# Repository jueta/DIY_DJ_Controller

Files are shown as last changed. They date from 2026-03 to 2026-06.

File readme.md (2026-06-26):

# DIY DJ Controller



Homemade CDJ-style DJ controller with a 3D-printed enclosure, hand-built electronics, and custom firmware.

This repository documents:
- the current stable Mixxx prototype
- the firmware and Mixxx mapping that make it work
- the next hardware direction for a cleaner v2 build
- open-source hardware, firmware, and documentation for builders who want to contribute

DIY DJ controller with blue buttons

DIY DJ controller with tools

<table>
  <tr>
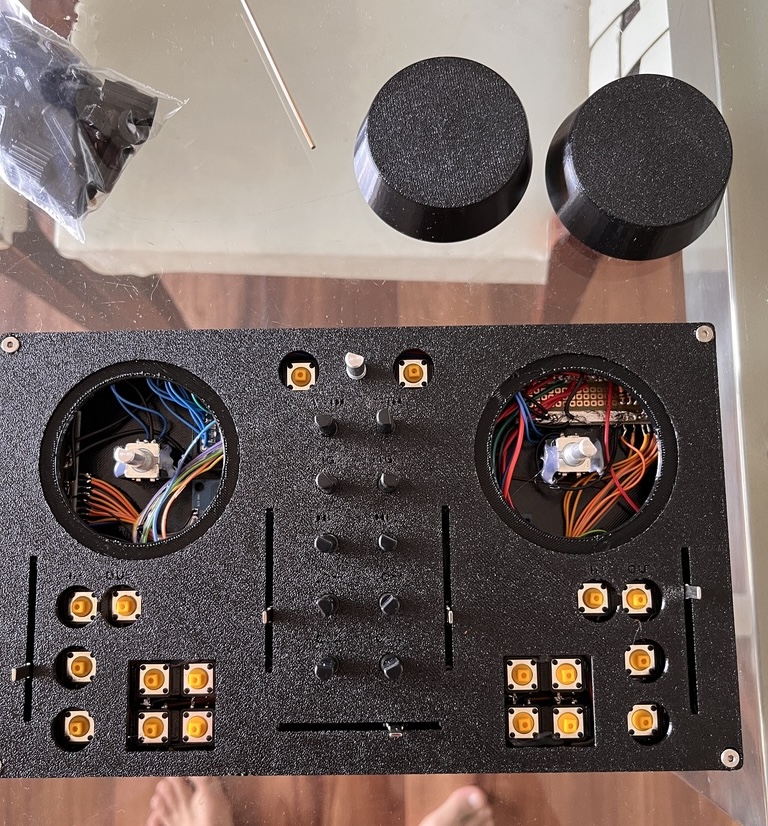
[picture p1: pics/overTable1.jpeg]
Prototype top view before final buttons
    <td></td>
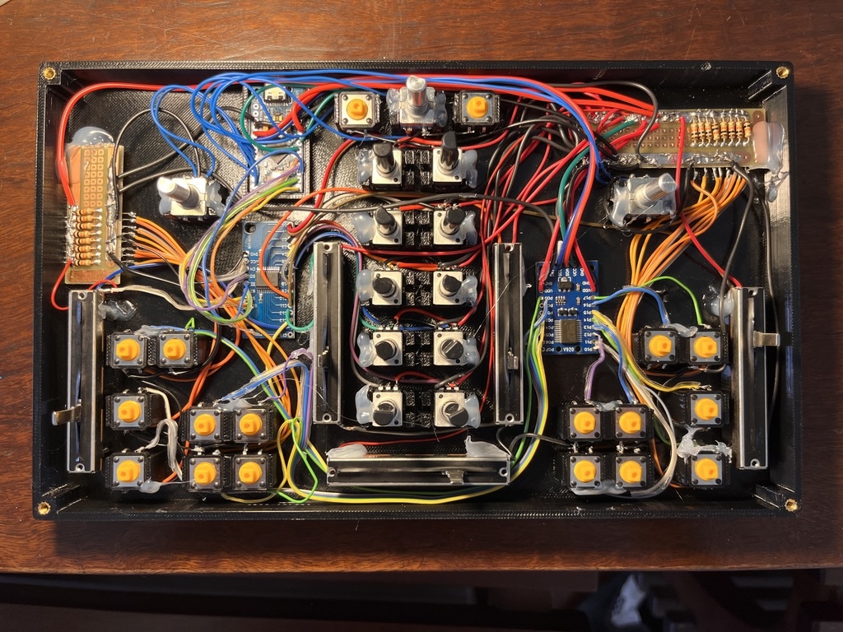
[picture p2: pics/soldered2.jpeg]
Hand-wired controller electronics
    <td></td>
  </tr>
  <tr>
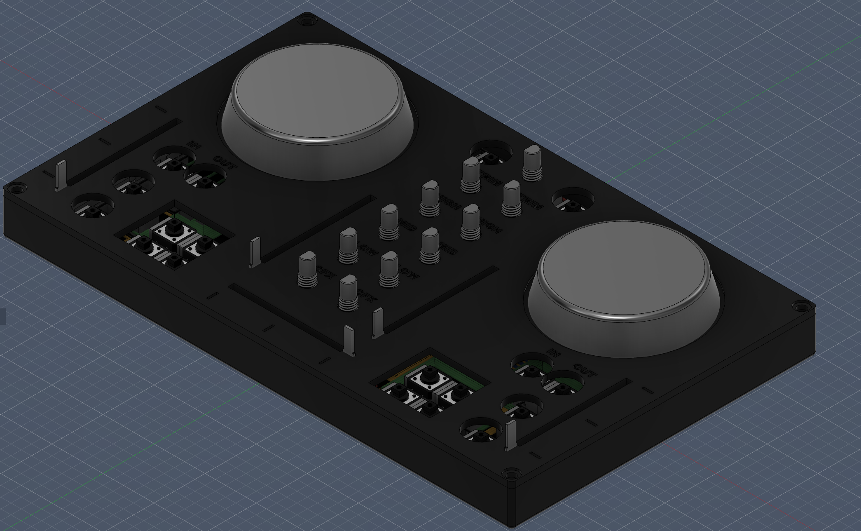
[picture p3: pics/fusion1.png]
Fusion 360 top assembly render
    <td></td>
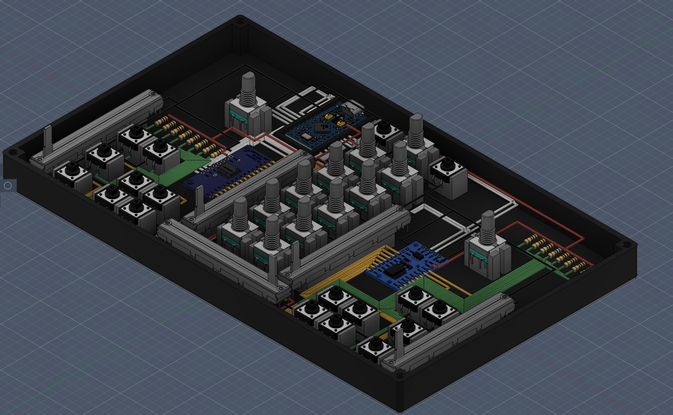
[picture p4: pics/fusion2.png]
Fusion 360 internal assembly render
    <td></td>
  </tr>
</table>

## Status

- `v1` is the stable Mixxx-focused version
- the controller has been built, flashed, and used successfully as a working prototype
- Rekordbox was tested, but the jog wheels never became usable enough for a real workflow
- because of that, Rekordbox is not a supported target for this hardware revision

## Current Version

- `MCU`: SparkFun Pro Micro / ATmega32U4
- `Firmware`: PlatformIO + Arduino + `MIDIUSB`
- `Inputs`: `PCF8575` for buttons, `74HC4067` for analog controls, 3 rotary encoders
- `Mechanical`: custom 3D-printed enclosure designed in Fusion 360
- `Software target`: Mixxx

The current prototype includes:
- two-deck transport and loop control
- EQ, filter, gain, volume, tempo, and crossfader control
- jog wheels
- music browsing and load controls

## V1 Hardware Summary

- `MCU`: SparkFun Pro Micro / ATmega32U4
- `Button expander`: `PCF8575` for 16 buttons
- `Analog mux`: `74HC4067` for 15 potentiometers
- `Encoders`: 3 total
  - 1 browse encoder
  - 2 jog wheel encoders
- `Encoder model`: Alps `EC11E` vertical rotary encoder, `H20mm`
- `Button model`: Omron `B3F-40xx`, 12x12 mm THT tactile switch
- `Direct buttons on MCU`: `A1`, `A2`, `A3`
- `Potentiometers`: 15 total
  - `Linear model`: `B103` 75 mm linear slide potentiometer, 10 kOhm
  - `Rotary model`: TT Electronics `P0915N` vertical rotary potentiometer

## V1 Materials List

This is the practical parts list for rebuilding the current working v1 prototype.

| Qty | Material | Notes |
| --- | --- | --- |
| 1 | 🧠 Microcontroller | Arduino Pro Micro - ATmega32U4 - USB Type C |
| 18 | 🔘 Buttons | B3F-4055 - 12x12x7.3mm |
| 3 | 🔄 Rotary Encoders | EC11 - 15mm shaft lenght - D shaft - without push button |
| 10 | 🎛️ Rotary Potentiometers | R0902N - B103 - 10kΩ - 23mm shaft lenght - D shaft |
| 5 | 🎚️ Slide Potentiometers | 60mm - B103 - 10kΩ - 15mm handle lenght |
| 1 | 🔘 Buttons pin expander | `PCF8575` / HW-331 16-bit I2C IO expander module |
| 1 | 🎛️ Potentiometers pin expander | `CD74HC4067` / `74HC4067` 16-channel analog multiplexer module |
| 1 | 3D-printed enclosure body | `3D models/DIY_CDJ_body.stl`. |
| 1 | 3D-printed enclosure lid | `3D models/DIY_CDJ_lid.stl`. |
| 1 each | 3D-printed caps and control parts | `crossfader.stl`, `cue.stl`, `encoder.stl`, `joggingWheel.stl`, `knob.stl`, `performance-pad.stl`, and `play-pause.stl`. |
| As needed | Hookup wire, solder, and 2.54 mm headers | The stable v1 prototype is hand-wired, not PCB-based. |

The firmware currently defines 3 direct music-selection inputs on `A1`, `A2`, and `A3`, but the KiCad v1 schematic places 18 tactile switches total. Add one extra switch if you wire all 3 direct inputs. The schematic also contains 16 resistor placeholders with no values or footprints assigned yet, so treat those as schematic TODOs rather than an order-ready BOM line.

## V1 Wiring Summary

These are the important firmware-defined connections for the current working Mixxx version.

### Wiring Diagrams

<p>
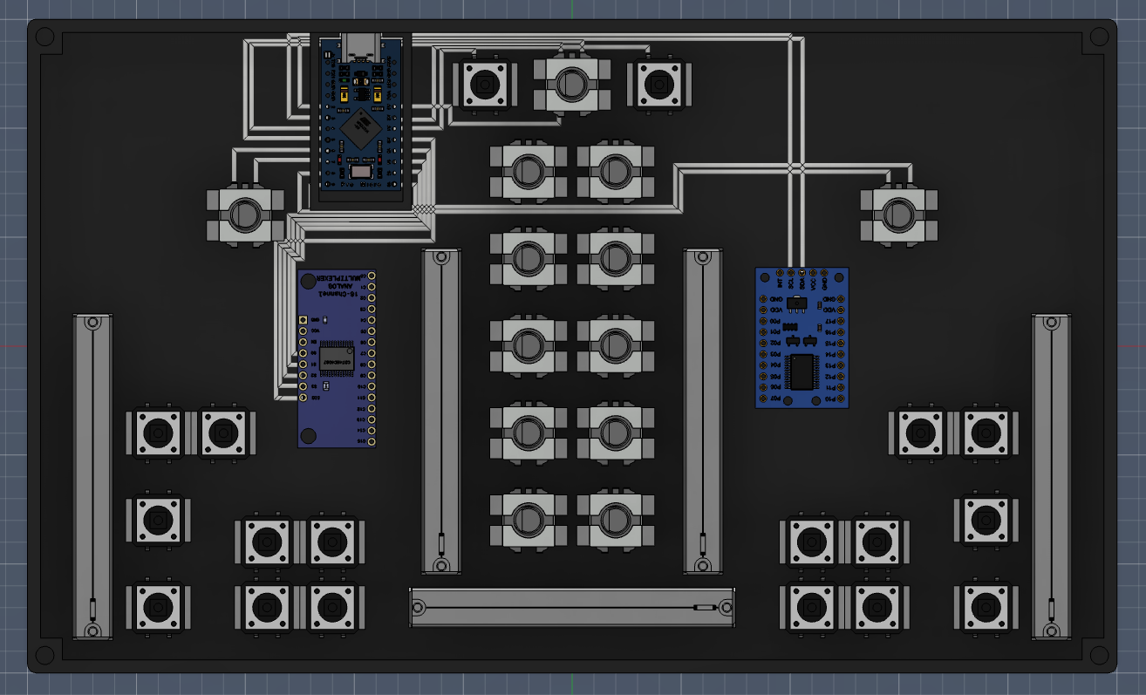
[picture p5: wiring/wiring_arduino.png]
Arduino wiring
  
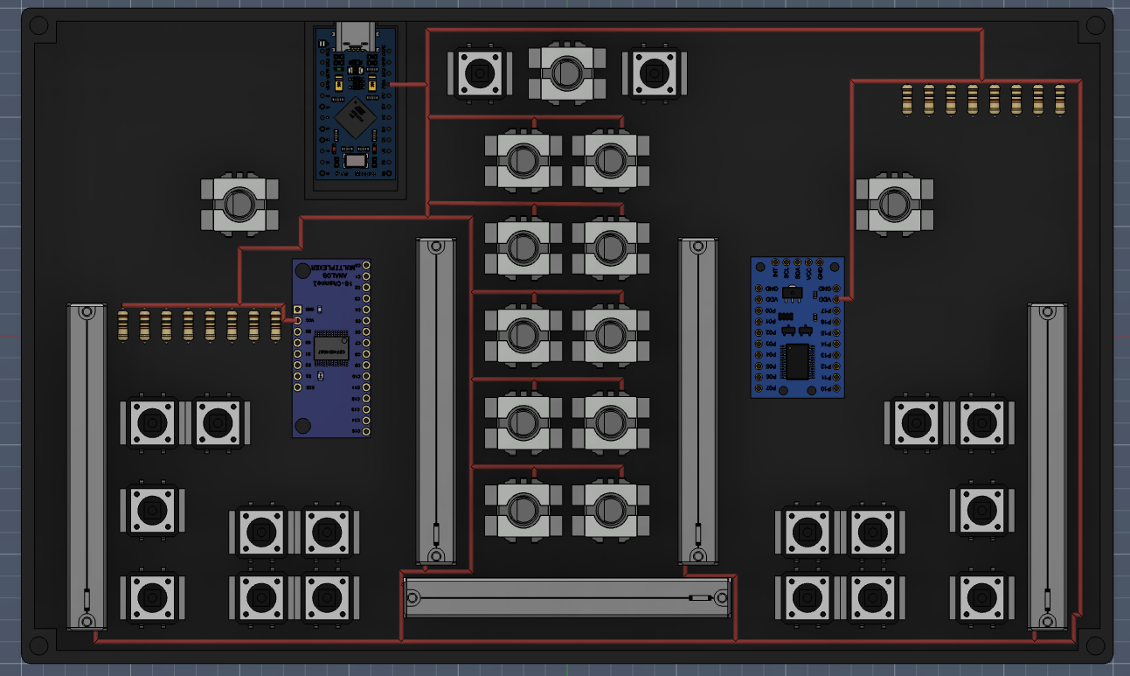
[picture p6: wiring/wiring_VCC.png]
VCC wiring
  
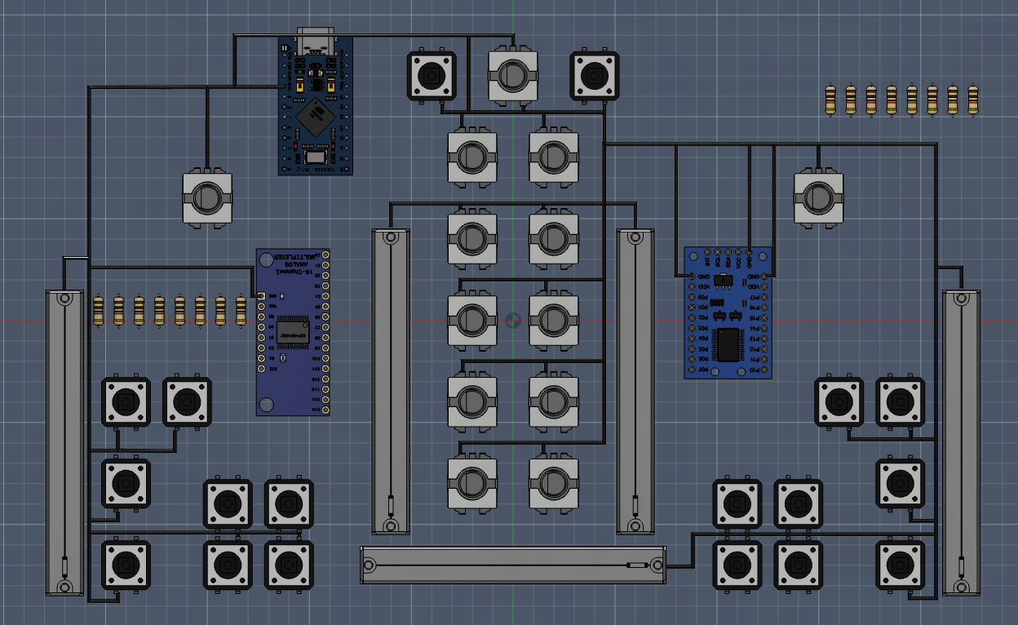
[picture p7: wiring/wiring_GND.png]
GND wiring
  
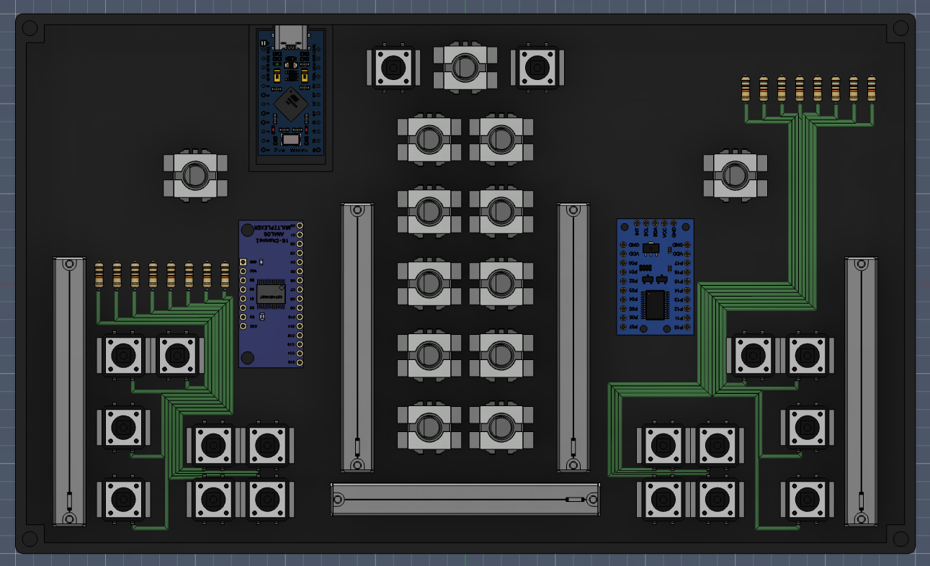
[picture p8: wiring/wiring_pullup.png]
Pull-up wiring
  
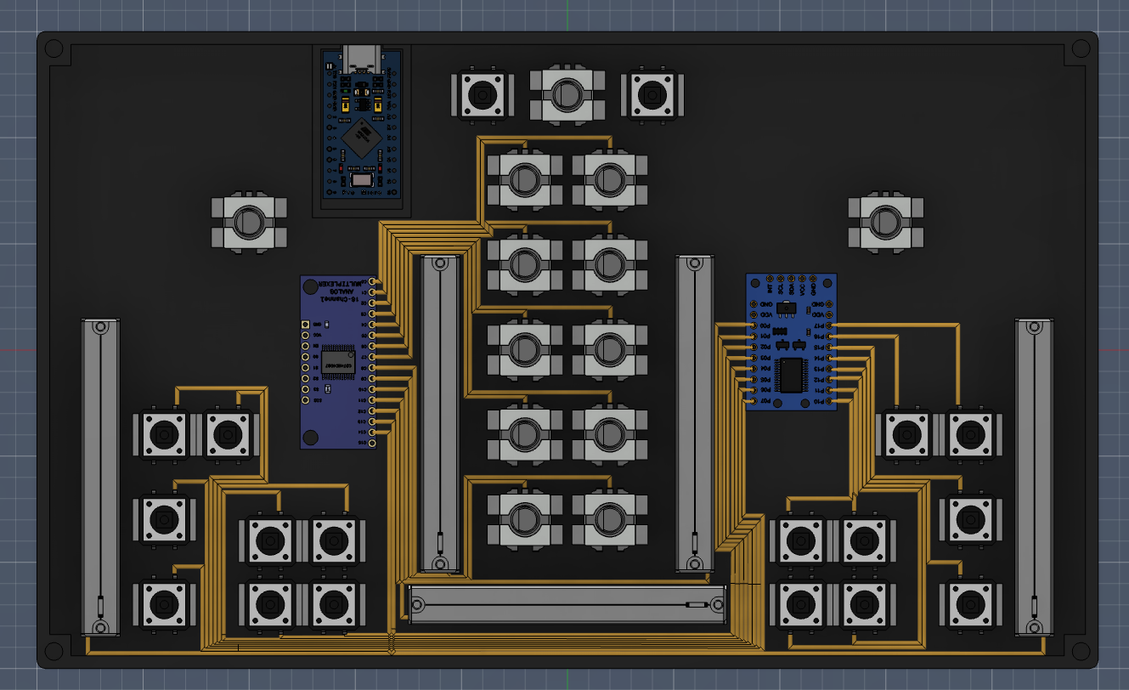
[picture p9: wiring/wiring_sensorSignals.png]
Sensor signal wiring
  
</p>

### I2C / Button Expander

- `SDA` -> pin `2`
- `SCL` -> pin `3`
- `PCF8575` address is auto-detected on boot in the `0x20` to `0x27` range

### 74HC4067 Multiplexer

- `MUX signal` -> `A0`
- `S0` -> pin `15`
- `S1` -> pin `14`
- `S2` -> pin `16`
- `S3` -> pin `10`

### Rotary Encoders

- `Browse encoder` -> pins `4` and `5`
- `Jog wheel 1` -> pins `8` and `9`
- `Jog wheel 2` -> pins `6` and `7`

### Direct Buttons

- `A3` -> note `76`
- `A2` -> note `77`
- `A1` -> note `78`

## V1 Current Input Map

### PCF8575 Buttons

- `Button 0` -> Deck 1 Loop Out
- `Button 1` -> Deck 1 Loop In
- `Button 2` -> Deck 1 Hotcue 3
- `Button 3` -> Deck 1 Hotcue 4
- `Button 4` -> Deck 1 Hotcue 1
- `Button 5` -> Deck 1 Hotcue 2
- `Button 6` -> Deck 1 Cue
- `Button 7` -> Deck 1 Play/Pause
- `Button 8` -> Deck 2 Hotcue 4
- `Button 9` -> Deck 2 Hotcue 3
- `Button 10` -> Deck 2 Hotcue 1
- `Button 11` -> Deck 2 Hotcue 2
- `Button 12` -> Deck 2 Cue
- `Button 13` -> Deck 2 Play/Pause
- `Button 14` -> Deck 2 Loop In
- `Button 15` -> Deck 2 Loop Out

### Potentiometers

- `Pot 0 / CC 10` -> Deck 1 Gain
- `Pot 1 / CC 11` -> Deck 2 Gain
- `Pot 2 / CC 12` -> Deck 1 High EQ
- `Pot 3 / CC 13` -> Deck 2 High EQ
- `Pot 4 / CC 14` -> Deck 1 Mid EQ
- `Pot 5 / CC 15` -> Deck 2 Mid EQ
- `Pot 6 / CC 16` -> Deck 1 Low EQ
- `Pot 7 / CC 17` -> Deck 2 Low EQ
- `Pot 8 / CC 18` -> Deck 1 Filter
- `Pot 9 / CC 19` -> Deck 2 Filter
- `Pot 10 / CC 20` -> Deck 2 Volume
- `Pot 11 / CC 21` -> Deck 2 Tempo
- `Pot 12 / CC 22` -> Deck 1 Volume
- `Pot 13 / CC 23` -> Crossfader
- `Pot 14 / CC 24` -> Deck 1 Tempo

### Browser And Jog Controls

- `Browse encoder / CC 25` -> library scroll
- `A1 / note 78` -> Load selected track to Deck 1
- `A2 / note 77` -> Load selected track to Deck 2
- `A3 / note 76` -> Enter or expand selected folder
- `Jog wheel on pins 8/9 / CC 26` -> currently mapped to Deck 2
- `Jog wheel on pins 6/7 / CC 27` -> currently mapped to Deck 1

## V1 Firmware

The current firmware lives in `CDJ_firmware/src/main.cpp`.

### Current Behavior

- auto-detects the `PCF8575` on boot
- configures the expander pins as input pull-high
- reads 16 buttons through the `PCF8575`
- reads 15 analog controls through the `74HC4067`
- reads 3 rotary encoders
- reads direct top buttons on `A1`, `A2`, and `A3`
- sends MIDI note and CC messages through `MIDIUSB`
- uses an additional filter on the browse encoder to reduce event spam in Mixxx

### Build Target

`CDJ_firmware/platformio.ini` currently targets:

```ini
[env:sparkfun_promicro16]
platform = atmelavr
board = sparkfun_promicro16
framework = arduino
lib_deps =
  arduino-libraries/MIDIUSB @ ^1.0.5
```

## Repo Layout

- `CDJ_firmware/` - firmware source and PlatformIO config
- `controllers/mixx_Mapping/` - Mixxx XML and JS mapping
- `controllers/rekordbox/` - Rekordbox mapping reference and notes
- `pics/` - renders and prototype photos
- `reference circuits/` - circuit reference images
- `PCB/` - KiCad schematic, PCB, and custom symbols/footprints
- `3D models/` - printable parts and Fusion 360 source archive
- `CONTRIBUTING.md` - contribution guide
- `.github/` - issue templates, pull request template, and CI workflow

## Source Of Truth

- `Firmware`: `CDJ_firmware/src/main.cpp`
- `Mixxx XML mapping`: `controllers/mixx_Mapping/DJC-DIY.midi.xml`
- `Mixxx JS mapping`: `controllers/mixx_Mapping/DJC-DIY-scripts.js`

For exact control behavior, use those files instead of this README.

## Contributing

Contributions are welcome. The most useful contributions right now are practical build reports, Mixxx mapping fixes, firmware cleanup, PCB review, parts substitutions, enclosure fit notes, and documentation improvements.

Before starting a large hardware or firmware change, open an issue so the direction can be discussed. Small documentation fixes can go straight to a pull request.

Useful starter work:

- test the current Mixxx mapping on another OS or Mixxx version
- document compatible Pro Micro clones, encoders, buttons, and potentiometers
- improve wiring photos or assembly notes
- review the KiCad v1 schematic and PCB TODOs
- add real build notes for 3D-print settings and fit adjustments

See `CONTRIBUTING.md` for the full workflow and pull request checklist.

## Getting Started

### Firmware

1. Install [PlatformIO](https://platformio.org/) in VS Code.
2. Open `CDJ_firmware/`.
3. Connect the SparkFun Pro Micro by USB.
4. Build or upload:

```bash
pio run
pio run --target upload
```

### Mixxx

Copy these files into your Mixxx controller mapping folder:

- `controllers/mixx_Mapping/DJC-DIY.midi.xml`
- `controllers/mixx_Mapping/DJC-DIY-scripts.js`

Then enable the mapping in Mixxx.

## Important Notes

- The stable path for this project is Mixxx, not Rekordbox.
- The prototype is still hand-wired and not PCB-based yet.
- The current jog wheel assignment is swapped between physical control and deck mapping.
- Rekordbox support should be treated as future hardware research, not a feature of this version.

## V2 Plan

V2 is a hardware redesign focused on one goal: keep a single `USB-C` cable to the computer and add a built-in `3.5 mm` headphone cue output.

- `Master` stays on the computer side
- the controller provides only `Headphones / Cue`
- the project stays Mixxx-first

### Electronics Plan

- `Prototype MCU`: `SparkFun Thing Plus ESP32-S3`
- `Custom PCB MCU`: `ESP32-S3-WROOM-1`
- `Headphone audio`: `Adafruit TLV320DAC3100` or equivalent small I2S headphone DAC/codec
- `External ports`: one `USB-C`, one `3.5 mm TRS` headphone jack
- `Existing controls to keep initially`: `PCF8575`, `74HC4067`, jog encoders, browse encoder, buttons, and potentiometers

### Core Connections

- `USB-C` -> `ESP32-S3`
- `ESP32-S3 I2S` -> `TLV320DAC3100` audio data
- `ESP32-S3 I2C` -> `TLV320DAC3100` configuration
- `TLV320DAC3100` -> `3.5 mm TRS` headphone jack
- `ESP32-S3` -> existing control hardware

### Firmware Work

- port the controller logic from `ATmega32U4` to `ESP32-S3`
- expose one composite USB device with `MIDI + audio`
- keep the current control behavior as close to `v1` as possible
- send Mixxx cue audio to the headphone DAC

### Rekordbox Note

`ESP32-S3` is a much better platform for future USB experiments, but it does not guarantee Rekordbox compatibility or working jog wheels. V2 should still be treated as a Mixxx-first design.

## License

This project uses separate licenses by file type:

| Files | License |
| --- | --- |
| Firmware and controller mappings | GNU General Public License v3.0 only (`GPL-3.0-only`) |
| PCB, wiring, CAD, and 3D hardware design files | CERN Open Hardware Licence Version 2 - Strongly Reciprocal (`CERN-OHL-S-2.0`) |
| Documentation, photos, videos, and other media | Creative Commons Attribution 4.0 International (`CC-BY-4.0`) |

See `LICENSE.md`, `LICENSE-SOFTWARE.txt`, `LICENSE-HARDWARE.txt`, and `LICENSE-DOCS.txt` for details.

This project was inspired by my friend [@mandiclab](https://github.com/mandiclab) and the [djc-diy](https://github.com/mandiclab/djc-diy) project.

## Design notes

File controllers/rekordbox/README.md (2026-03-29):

# Rekordbox Mapping

This folder contains a Rekordbox mapping reference for the DIY DJ controller.

## Important Limitation

Rekordbox supports MIDI Learn and can export/import MIDI mappings as CSV, but AlphaTheta does not publicly document the CSV schema. That means this folder provides:

- a complete mapping reference CSV for manual setup in Rekordbox
- a workflow for exporting your own Rekordbox CSV and adapting it later

If you export a sample MIDI CSV from your installed Rekordbox version, it can be converted into a true importable file using the same mapping in this folder.

## Intended Behavior

This mapping follows the current working controller behavior already used for Mixxx:

- Deck 1 and Deck 2 transport
- loop in / out
- four function buttons per deck
- gain, EQ, filter, volume, tempo
- crossfader
- library browse encoder
- load to Deck 1 / Deck 2
- enter / expand folder

## Recommended Rekordbox Setup Flow

1. Open Rekordbox in `PERFORMANCE` mode.
2. Connect the controller by USB.
3. Open the `MIDI` panel.
4. Use `LEARN` to assign controls one by one using `DJC-DIY-rekordbox-reference.csv`.
5. Export the finished mapping as a CSV from Rekordbox.
6. Save that exported CSV in this folder so it becomes the true import file for your exact Rekordbox version.

## Files

- `DJC-DIY-rekordbox-reference.csv` - manual mapping reference

## Notes

- Jog behavior in Rekordbox may require extra testing compared with Mixxx.
- The browse and load controls are included in the reference, but Rekordbox library mappings can vary slightly by version and focus state.
- If you export a Rekordbox MIDI CSV, the next step is to place it in this folder and use it as the canonical Rekordbox mapping file.

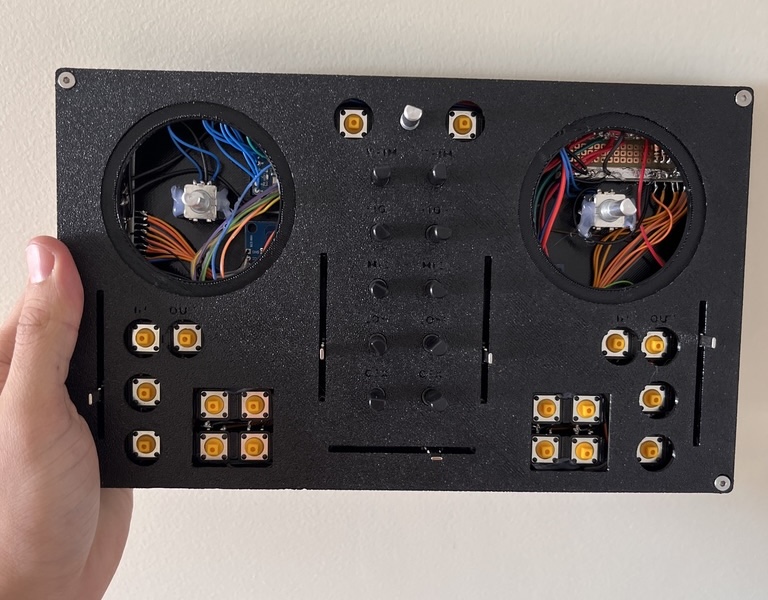
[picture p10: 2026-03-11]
pics/hands.jpeg

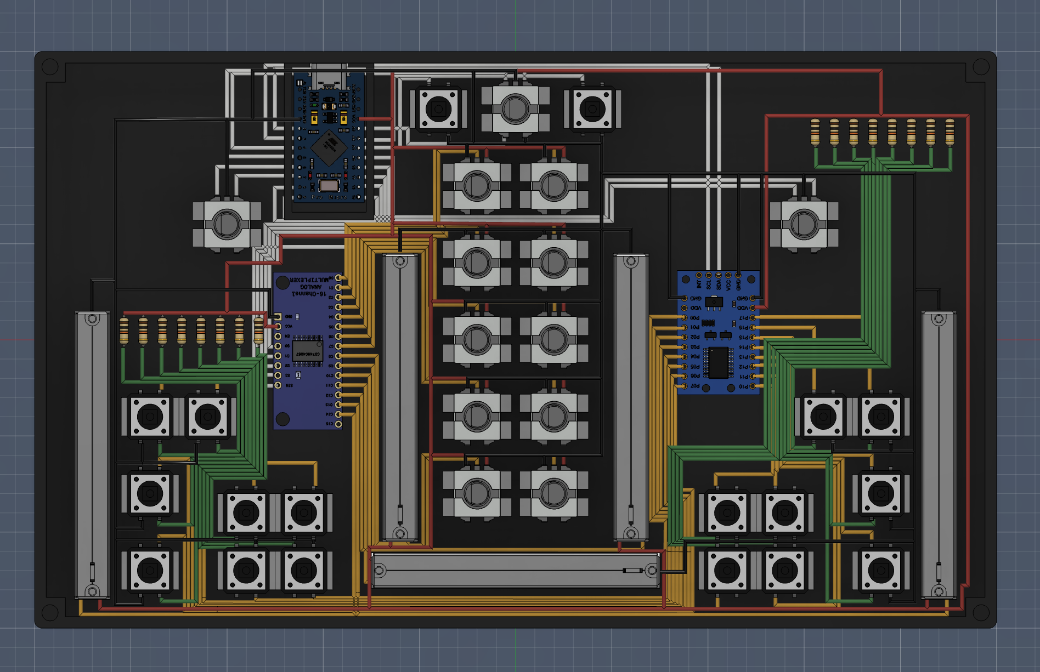
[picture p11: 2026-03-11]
pics/fusion3.png

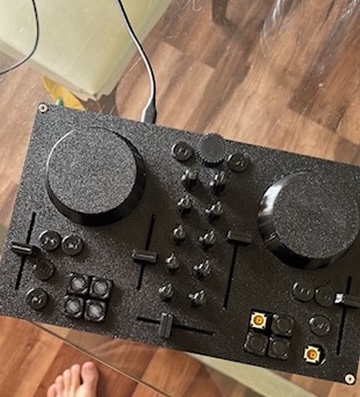
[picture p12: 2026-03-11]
pics/overTable2.jpeg

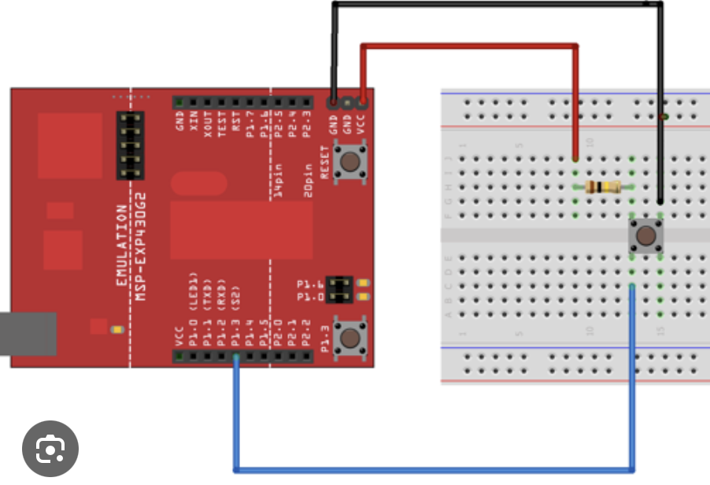
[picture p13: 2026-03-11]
reference circuits/Screenshot 2026-01-16 at 19.17.38.png

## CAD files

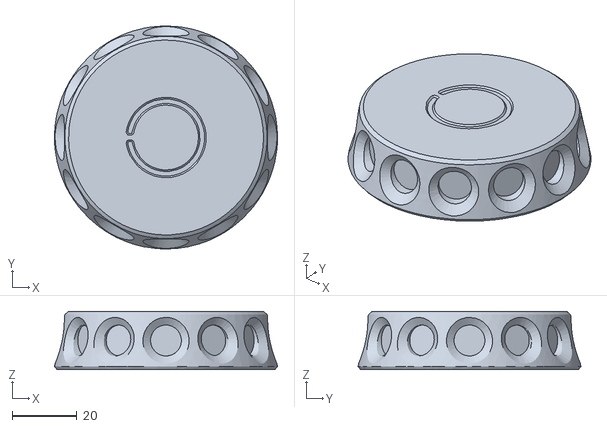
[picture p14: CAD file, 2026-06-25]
3D models/manda_jogwheel_big.stl
69.0 x 69.0 x 18.0

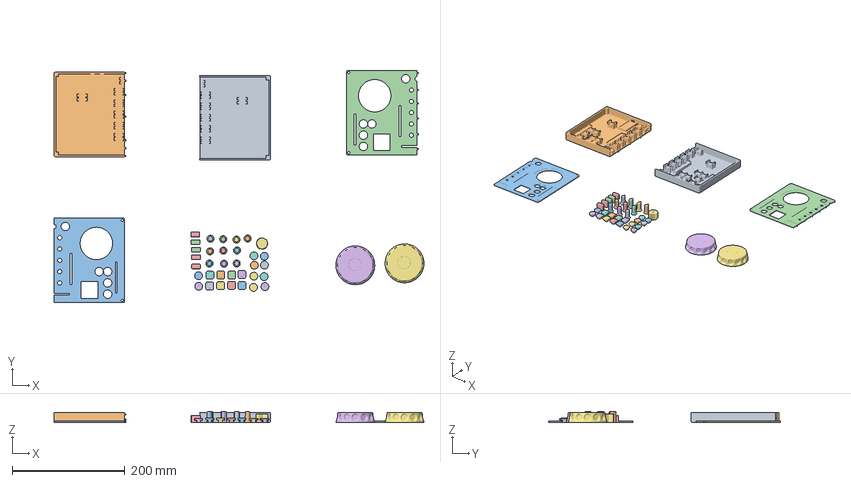
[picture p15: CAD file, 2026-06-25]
3D models/Orca_Slicer_Files/DIY_CDJ.3mf
656.0 x 411.9 x 20.0 mm
DIY_CDJ_body.stl x 2
DIY_CDJ_lid.stl_A
DIY_CDJ_lid.stl_B
crossfader.stl x 5
cue.stl x 2
encoder.stl
knob.stl x 10
performance-pad.stl x 8
play-pause.stl x 2
button_load_track.stl
button_round_clean.stl x 4
manda_jogwheel_big.stl x 2

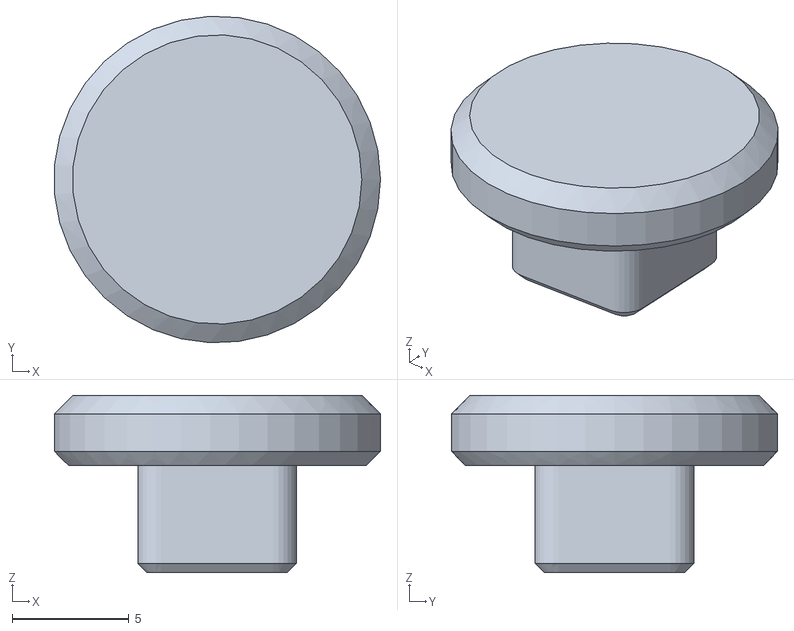
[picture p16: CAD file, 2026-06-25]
3D models/button_round_clean.stl
14.0 x 14.0 x 7.60

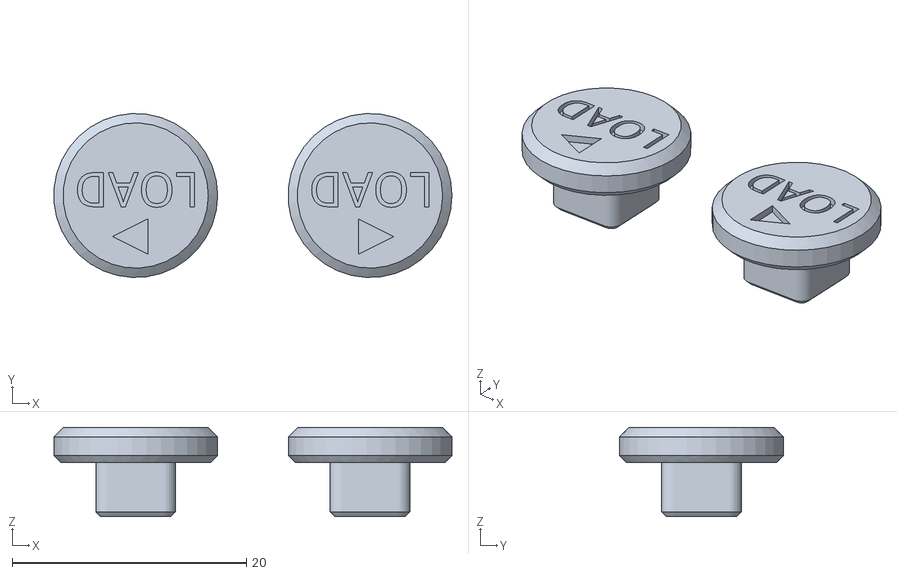
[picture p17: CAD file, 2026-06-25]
3D models/button_load_track.stl
34.0 x 14.0 x 7.60

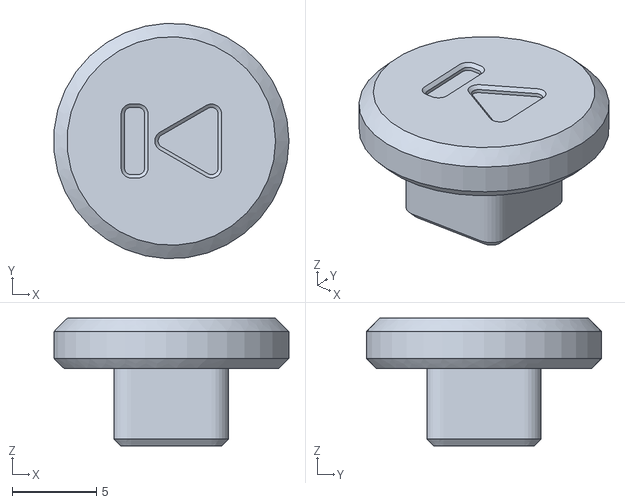
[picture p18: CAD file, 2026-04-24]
3D models/cue.stl
14.0 x 14.0 x 7.60

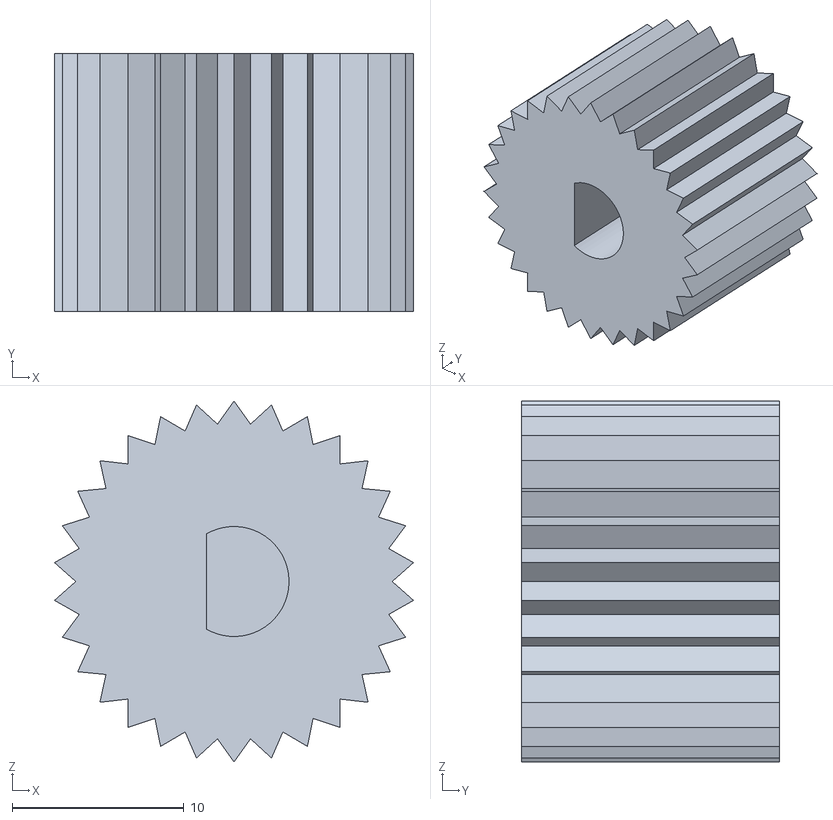
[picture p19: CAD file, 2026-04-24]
3D models/encoder.stl
20.9 x 15.0 x 21.0

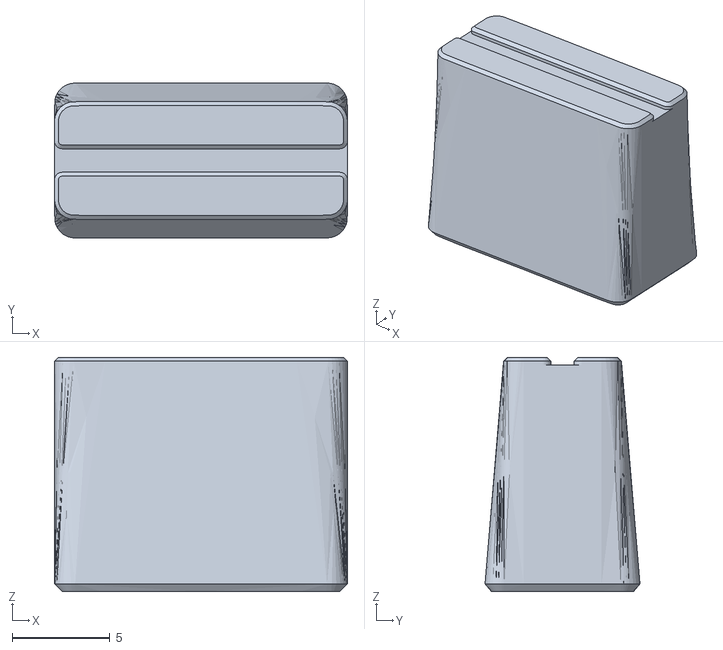
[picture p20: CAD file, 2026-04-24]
3D models/crossfader.stl
15.0 x 7.93 x 12.0

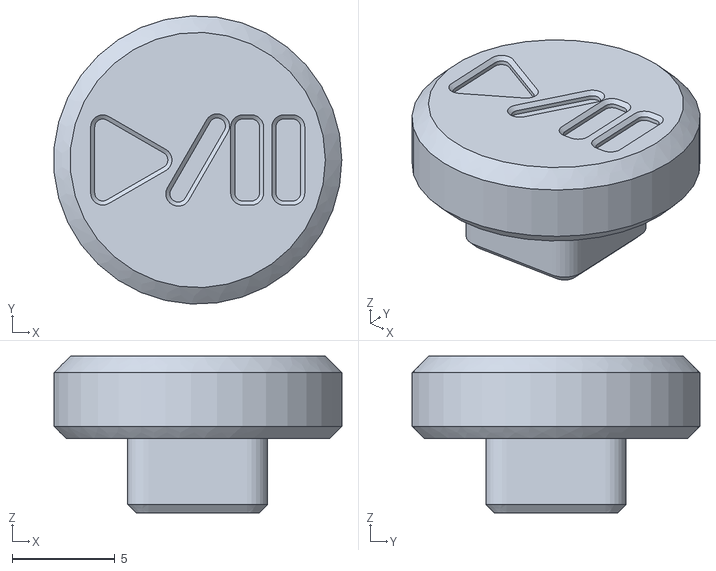
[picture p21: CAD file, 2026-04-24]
3D models/play-pause.stl
14.0 x 14.0 x 7.60

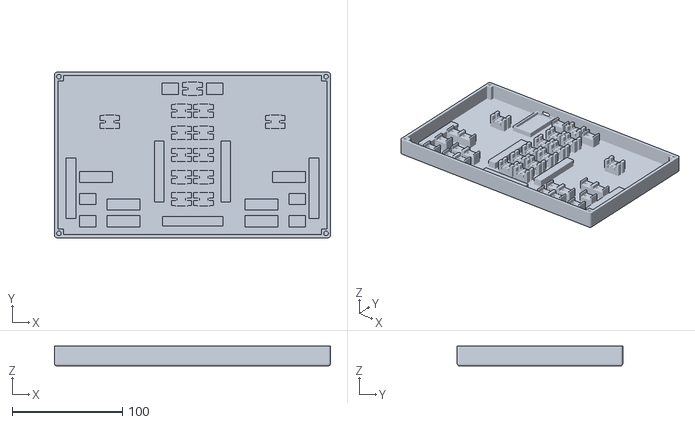
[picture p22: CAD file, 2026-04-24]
3D models/DIY_CDJ_body.stl
250.0 x 150.0 x 18.0

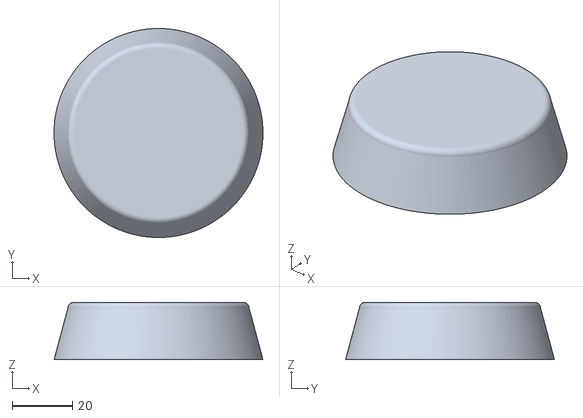
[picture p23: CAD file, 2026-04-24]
3D models/joggingWheel.stl
69.1 x 69.1 x 19.0

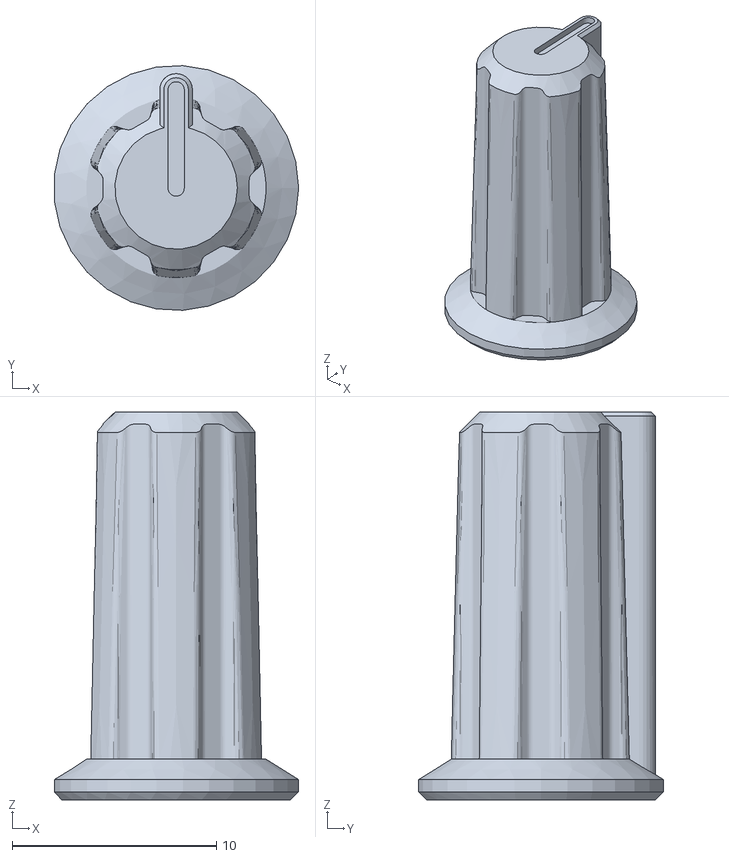
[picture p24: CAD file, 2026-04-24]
3D models/knob.stl
12.0 x 12.0 x 19.0

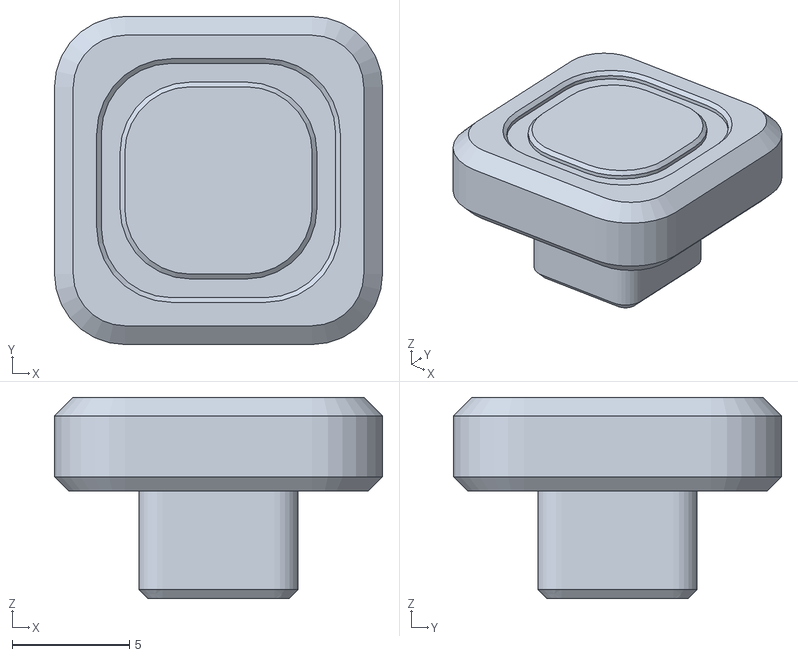
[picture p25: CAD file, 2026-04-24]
3D models/performance-pad.stl
14.0 x 14.0 x 8.60

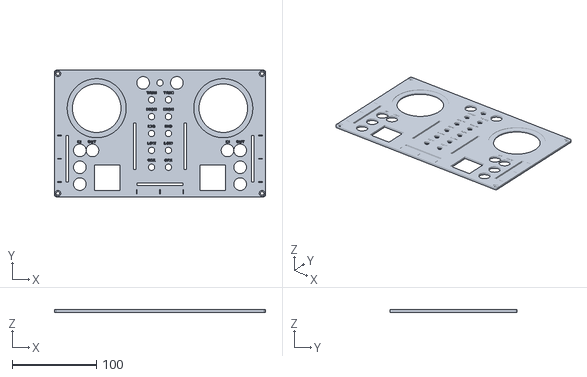
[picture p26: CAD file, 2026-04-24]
3D models/DIY_CDJ_lid.stl
250.0 x 150.0 x 3.00

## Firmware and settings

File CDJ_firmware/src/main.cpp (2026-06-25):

#include <Arduino.h>
#include <MIDIUSB.h>
#include <Wire.h>

// ---------- PCF8575 IO EXPANDER (16 PUSH BUTTONS) ----------
// PCF8575 address is detected on boot across the valid 0x20-0x27 range.
const byte PCF8575_ADDR_START = 0x20;
const byte PCF8575_ADDR_END = 0x27;
byte pcf8575Addr = 0;
const byte buttonNotes[] = {60, 61, 62, 63, 64, 65, 66, 67, 68, 69, 70, 71, 72, 73, 74, 75};
bool buttonStates[16] = {0};

// ---------- 74HC4067 MULTIPLEXER (15 POTENTIOMETERS) ----------
// Selection pins for the multiplexer
const int MUX_S0 = 15;
const int MUX_S1 = 14;
const int MUX_S2 = 16;
const int MUX_S3 = 10;
const int MUX_INPUT = A0; // Analog input from multiplexer

const byte potCCs[] = {10, 11, 12, 13, 14, 15, 16, 17, 18, 19, 20, 21, 22, 23, 24};
int potValues[15] = {0};
const int potThreshold = 2;

// ---------- ROTARY ENCODERS ----------
// Music selection encoder (top middle)
const int encoderA_Music = 4;
const int encoderB_Music = 5;
const byte encoderCC_Music = 25;
bool encoderLastState_Music = 0;

// Jog wheel encoder 1
const int encoderA_Jog1 = 8;
const int encoderB_Jog1 = 9;
const byte encoderCC_Jog1 = 26;
bool encoderLastState_Jog1 = 0;

// Jog wheel encoder 2
const int encoderA_Jog2 = 6;
const int encoderB_Jog2 = 7;
const byte encoderCC_Jog2 = 27;
bool encoderLastState_Jog2 = 0;

// ---------- PUSH BUTTONS ON ARDUINO PINS (with software pullup) ----------
// Music selection buttons (top)
const int buttonPin_A3 = A3;
const int buttonPin_A2 = A2;
const int buttonPin_A1 = A1;
const byte buttonNote_A3 = 76;
const byte buttonNote_A2 = 77;
const byte buttonNote_A1 = 78;
bool buttonState_A3 = false;
bool buttonState_A2 = false;
bool buttonState_A1 = false;

// ---------- FUNCTION DECLARATIONS ----------
void noteOn(byte pitch);
void noteOff(byte pitch);
void handlePots();
void selectMuxChannel(int channel);
void sendCC(byte cc, byte val);
void handleEncoders();
uint16_t readPCF8575();
bool detectPCF8575();
void configurePCF8575Inputs();

void setup()
{
   Serial.begin(115200);
   delay(1000);
  // Serial.println("Booting DJ controller...");

  // Initialize I2C for PCF8575
  Wire.begin();
  delay(500); // Give I2C time to initialize

  if (detectPCF8575())
  {
    configurePCF8575Inputs();
    // Serial.print("PCF8575 detected at 0x");
    // Serial.println(pcf8575Addr, HEX);
  }
  else
  {
    // Serial.println("No PCF8575 found on I2C addresses 0x20-0x27");
  }

  // Initialize multiplexer selection pins
  pinMode(MUX_S0, OUTPUT);
  pinMode(MUX_S1, OUTPUT);
  pinMode(MUX_S2, OUTPUT);
  pinMode(MUX_S3, OUTPUT);

  // Initialize music selection encoder pins
  pinMode(encoderA_Music, INPUT_PULLUP);
  pinMode(encoderB_Music, INPUT_PULLUP);
  encoderLastState_Music = digitalRead(encoderA_Music);

  // Initialize jog wheel encoder 1 pins
  pinMode(encoderA_Jog1, INPUT_PULLUP);
  pinMode(encoderB_Jog1, INPUT_PULLUP);
  encoderLastState_Jog1 = digitalRead(encoderA_Jog1);

  // Initialize jog wheel encoder 2 pins
  pinMode(encoderA_Jog2, INPUT_PULLUP);
  pinMode(encoderB_Jog2, INPUT_PULLUP);
  encoderLastState_Jog2 = digitalRead(encoderA_Jog2);

  // Initialize music selection button pins with software pullup
  pinMode(buttonPin_A3, INPUT_PULLUP);
  pinMode(buttonPin_A2, INPUT_PULLUP);
  pinMode(buttonPin_A1, INPUT_PULLUP);
}

void loop()
{
  // ------------------ PUSH BUTTONS (PCF8575) ------------------
  uint16_t buttonData = readPCF8575();

  for (int i = 0; i < 16; i++)
  {
    bool pressed = !(bitRead(buttonData, i)); // Active LOW

    if (pressed && !buttonStates[i])
    {
       Serial.print("Button ");
       Serial.print(i);
       Serial.print(" pressed - Note: ");
       Serial.println(buttonNotes[i]);

      noteOn(buttonNotes[i]);
      buttonStates[i] = true;
    }
    else if (!pressed && buttonStates[i])
    {
      // Serial.print("Button ");
      // Serial.print(i);
      // Serial.println(" released");

      noteOff(buttonNotes[i]);
      buttonStates[i] = false;
    }
  }

  // ------------------ MUSIC SELECTION BUTTONS (A3, A2, A1) ------------------
  // Button on A3
  bool pressedA3 = !digitalRead(buttonPin_A3);
  if (pressedA3 && !buttonState_A3)
  {
    // Serial.println("Button A3 pressed - Note: 76");
    noteOn(buttonNote_A3);
    buttonState_A3 = true;
  }
  else if (!pressedA3 && buttonState_A3)
  {
    // Serial.println("Button A3 released");
    noteOff(buttonNote_A3);
    buttonState_A3 = false;
  }

  // Button on A2
  bool pressedA2 = !digitalRead(buttonPin_A2);
  if (pressedA2 && !buttonState_A2)
  {
    // Serial.println("Button A2 pressed - Note: 77");
    noteOn(buttonNote_A2);
    buttonState_A2 = true;
  }
  else if (!pressedA2 && buttonState_A2)
  {
    // Serial.println("Button A2 released");
    noteOff(buttonNote_A2);
    buttonState_A2 = false;
  }

  // Button on A1
  bool pressedA1 = !digitalRead(buttonPin_A1);
  if (pressedA1 && !buttonState_A1)
  {
    // Serial.println("Button A1 pressed - Note: 78");
    noteOn(buttonNote_A1);
    buttonState_A1 = true;
  }
  else if (!pressedA1 && buttonState_A1)
  {
    // Serial.println("Button A1 released");
    noteOff(buttonNote_A1);
    buttonState_A1 = false;
  }

  handlePots();

  handleEncoders();

  delay(2); // Reduced debounce for faster response
}

// ------------------ MIDI FUNCTIONS ------------------

void noteOn(byte pitch)
{
  midiEventPacket_t noteOnMsg = {0x09, 0x90, pitch, 127};
  MidiUSB.sendMIDI(noteOnMsg);
  MidiUSB.flush();
}

void noteOff(byte pitch)
{
  midiEventPacket_t noteOffMsg = {0x08, 0x80, pitch, 0};
  MidiUSB.sendMIDI(noteOffMsg);
  MidiUSB.flush();
}

void handlePots()
{
  static unsigned long lastReadTime = 0;
  const unsigned long readInterval = 5; // Faster polling (was 10ms)

  if (millis() - lastReadTime < readInterval)
    return;
  lastReadTime = millis();

  for (int i = 0; i < 15; i++)
  {
    // Select the channel on the multiplexer
    selectMuxChannel(i);

    // Read the analog value
    int raw = analogRead(MUX_INPUT);
    int mapped = raw / 8;

    if (abs(mapped - potValues[i]) >= potThreshold)
    {
      // Serial.print("Pot ");
      // Serial.print(i);
      // Serial.print(" (CC ");
      // Serial.print(potCCs[i]);
      // Serial.print("): ");
      // Serial.println(mapped);

      potValues[i] = mapped;
      sendCC(potCCs[i], mapped);
    }
  }
}

// Select channel on 74HC4067 multiplexer
void selectMuxChannel(int channel)
{
  digitalWrite(MUX_S0, bitRead(channel, 0));
  digitalWrite(MUX_S1, bitRead(channel, 1));
  digitalWrite(MUX_S2, bitRead(channel, 2));
  digitalWrite(MUX_S3, bitRead(channel, 3));
  delayMicroseconds(5); // Reduced settling time for faster response
}

void sendCC(byte cc, byte val)
{
  midiEventPacket_t ccMsg = {0x0B, 0xB0, cc, val};
  MidiUSB.sendMIDI(ccMsg);
  MidiUSB.flush();
}

void handleEncoders()
{
  static unsigned long lastMusicEncoderEventTime = 0;
  const unsigned long musicEncoderIntervalMs = 8;

  // ---------- MUSIC SELECTION ENCODER (pins 4, 5) ----------
  int currentState_Music = digitalRead(encoderA_Music);
  if (currentState_Music != encoderLastState_Music)
  {
    unsigned long now = millis();
    int bState = digitalRead(encoderB_Music);
    encoderLastState_Music = currentState_Music;

    if (now - lastMusicEncoderEventTime >= musicEncoderIntervalMs)
    {
      // Only emit on one edge of phase A to avoid double-triggering per detent.
      if (currentState_Music == LOW)
      {
        byte directionValue;

        if (currentState_Music == bState)
        {
          directionValue = 0x41;
          // Serial.println("Music Encoder - CW");
        }
        else
        {
          directionValue = 0x3F;
          // Serial.println("Music Encoder - CCW");
        }

        midiEventPacket_t cc = {0x0B, 0xB0, encoderCC_Music, directionValue};
        MidiUSB.sendMIDI(cc);
        MidiUSB.flush();
        lastMusicEncoderEventTime = now;
      }
    }
  }

  // ---------- JOG WHEEL ENCODER 1 (pins 8, 9) ----------
  int currentState_Jog1 = digitalRead(encoderA_Jog1);
  if (currentState_Jog1 != encoderLastState_Jog1)
  {
    int bState = digitalRead(encoderB_Jog1);
    byte directionValue;

    if (currentState_Jog1 == bState)
    {
      directionValue = 0x41;
      // Serial.println("Jog Wheel 1 - CW");
    }
    else
    {
      directionValue = 0x3F;
      // Serial.println("Jog Wheel 1 - CCW");
    }

    midiEventPacket_t cc = {0x0B, 0xB0, encoderCC_Jog1, directionValue};
    MidiUSB.sendMIDI(cc);
    MidiUSB.flush();

    encoderLastState_Jog1 = currentState_Jog1;
  }

  // ---------- JOG WHEEL ENCODER 2 (pins 6, 7) ----------
  int currentState_Jog2 = digitalRead(encoderA_Jog2);
  if (currentState_Jog2 != encoderLastState_Jog2)
  {
    int bState = digitalRead(encoderB_Jog2);
    byte directionValue;

    if (currentState_Jog2 == bState)
    {
      directionValue = 0x41;
      // Serial.println("Jog Wheel 2 - CW");
    }
    else
    {
      directionValue = 0x3F;
      // Serial.println("Jog Wheel 2 - CCW");
    }

    midiEventPacket_t cc = {0x0B, 0xB0, encoderCC_Jog2, directionValue};
    MidiUSB.sendMIDI(cc);
    MidiUSB.flush();

    encoderLastState_Jog2 = currentState_Jog2;
  }
}

// ---------- PCF8575 I2C FUNCTIONS ----------

// Read all 16 inputs from PCF8575 as a 16-bit value
uint16_t readPCF8575()
{
  static unsigned long lastWarning = 0;

  if (pcf8575Addr == 0)
  {
    if (millis() - lastWarning > 1000)
    {
      // Serial.println("Skipping PCF8575 read: no expander detected");
      lastWarning = millis();
    }
    return 0xFFFF;
  }

  Wire.requestFrom(pcf8575Addr, (uint8_t)2); // Request 2 bytes

  uint8_t low = 0xFF; // Default to all 1s (unpressed)
  uint8_t high = 0xFF;

  if (Wire.available() >= 1)
  {
    low = Wire.read();
  }
  if (Wire.available() >= 1)
  {
    high = Wire.read();
  }

  // Combine into 16-bit value
  uint16_t value = ((uint16_t)high << 8) | low;
  return value;
}

bool detectPCF8575()
{
  for (byte addr = PCF8575_ADDR_START; addr <= PCF8575_ADDR_END; addr++)
  {
    Wire.beginTransmission(addr);
    byte error = Wire.endTransmission();
    if (error == 0)
    {
      pcf8575Addr = addr;
      return true;
    }
  }

  pcf8575Addr = 0;
  return false;
}

void configurePCF8575Inputs()
{
  // PCF8575 uses quasi-bidirectional pins. Writing HIGH configures pins as inputs.
  Wire.beginTransmission(pcf8575Addr);
  Wire.write(0xFF);
  Wire.write(0xFF);
  byte error = Wire.endTransmission();

  if (error == 0)
  {
     Serial.println("PCF8575 configured for input pull-high");
  }
  else
  {
     Serial.print("PCF8575 init write failed, error=");
     Serial.println(error);
  }
}

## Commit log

2026-03-12 [MOTH] Add docs folder structure and kanban board
2026-03-29 Included rekordbox mapping file but jogwheels still missing
    [DJC-DIY-rekordbox-reference.csv, DJC-DIY.midi.csv]
2026-03-29 Refactor encoder handling and update README for clarity on Mixxx and Rekordbox support
    [DJC-DIY.midi.csv]
2026-04-06 reverting main.cpp to only mixxx working.
    [main.cpp]
2026-04-24 more documentation files
    [DIY_CDJ_body.stl, DIY_CDJ_lid.stl, crossfader.stl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]
2026-06-26 Updating list of materials
